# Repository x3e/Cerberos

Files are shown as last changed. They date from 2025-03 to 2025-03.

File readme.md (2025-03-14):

# Cerberos

## Issue
The screen is not working when powered from USB. In theory the internal CH552 voltage regulator should be able to provide enough current, and with a previous batch of screens, this was working. If you find the issue, please let us know by opening an issue or submitting a pull request.

## Compilation
To compile the software for this project, follow the instructions in the [ch55xduino](https://github.com/DeqingSun/ch55xduino) repository to set up your development environment. Use the following settings after selecting the CH552 board in Arduino:
 - Bootloader pin: P3.6 (D+) pull-up
 - Clock Source: 12 MHz (internal)
 - Upload method: USB
 - USB Settings: User Code w/ 0B USB ram

## License
This project is licensed under the Unlicense License. See the [LICENSE](LICENSE) file for details.

## Contact
If you have any questions or suggestions, feel free to open an issue.

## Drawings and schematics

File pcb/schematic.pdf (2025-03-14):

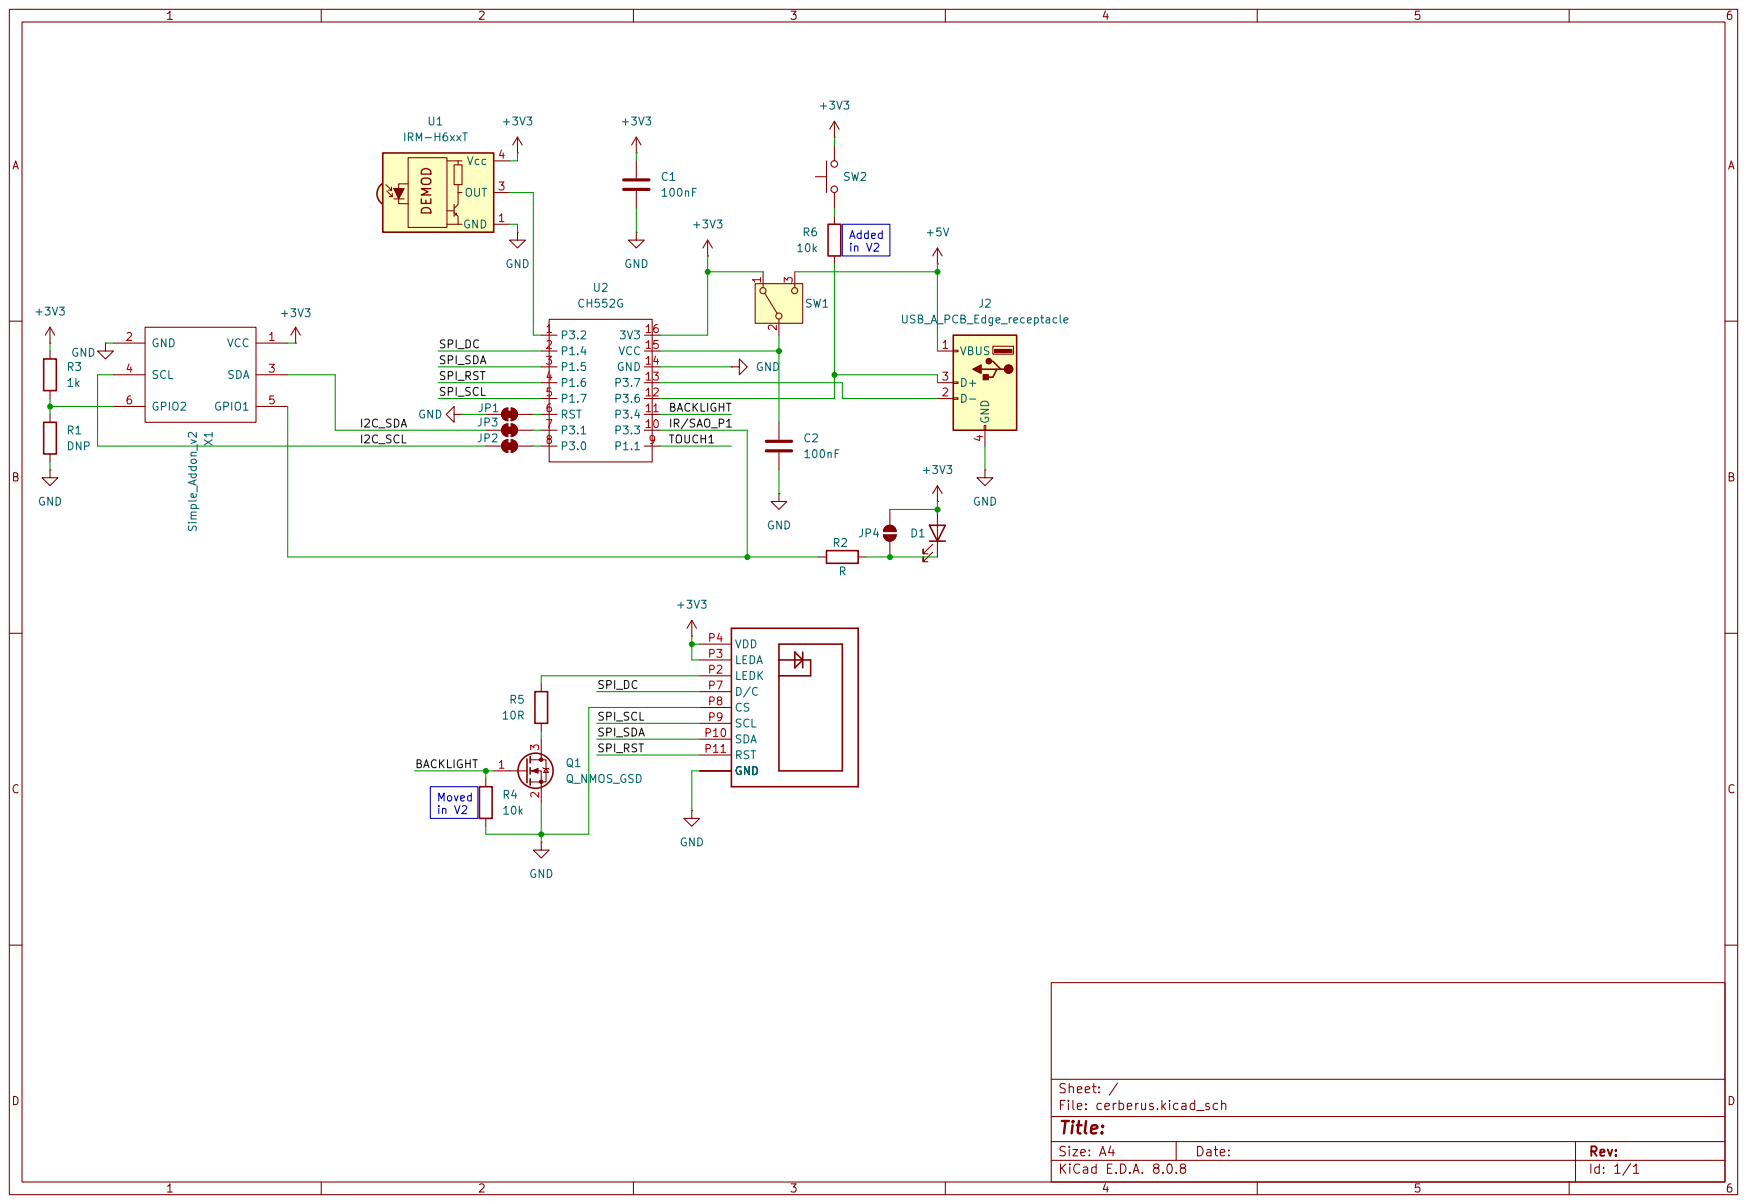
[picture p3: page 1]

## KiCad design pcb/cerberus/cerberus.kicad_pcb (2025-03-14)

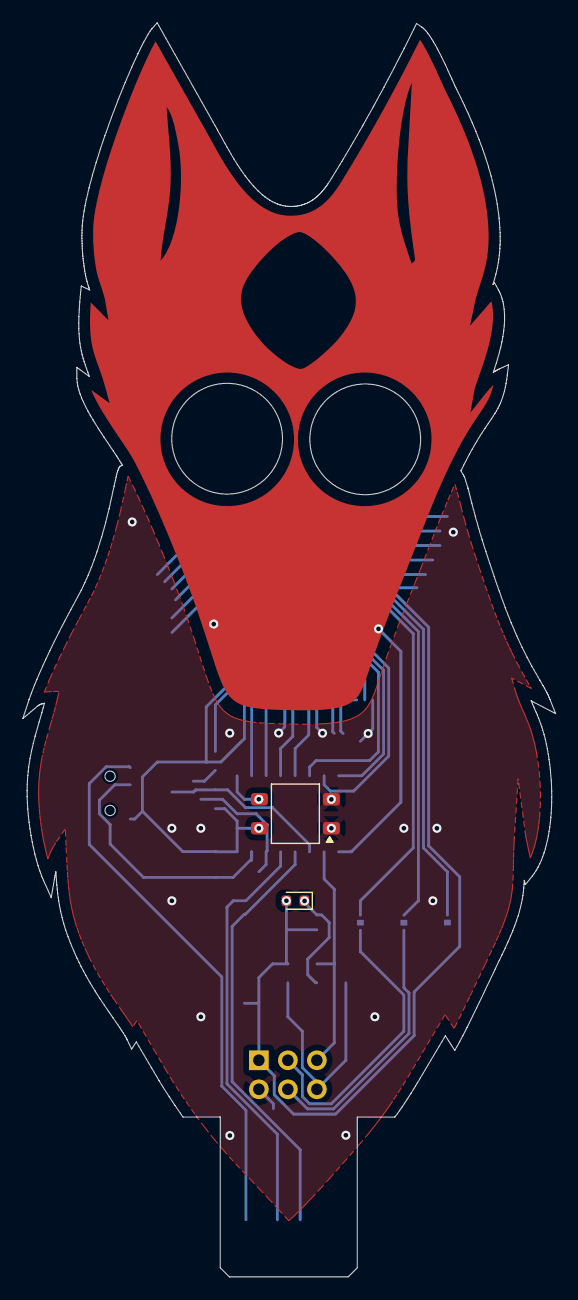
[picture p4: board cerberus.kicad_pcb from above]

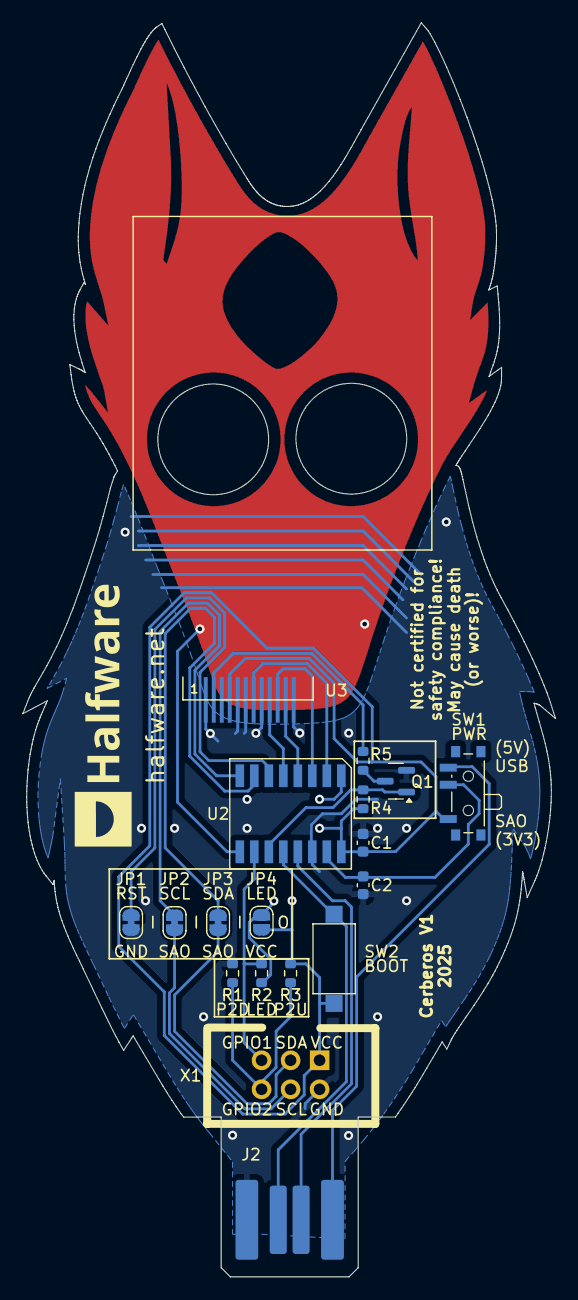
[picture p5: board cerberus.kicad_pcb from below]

Board: 2 copper layers, 46.7 x 109.8 mm, 20 parts (17 on the bottom side), 22 nets.

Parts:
C1, C2: 100nF; C_0603_1608Metric
D1: LED; LED_0603_1608Metric
J2: USB_A_PCB_Edge_receptacle
JP1, JP2, JP3: SolderJumper_2_Bridged; SolderJumper-2_P1.3mm_Bridged_RoundedPad1.0x1.5mm
JP4: SolderJumper_2_Open; SolderJumper-2_P1.3mm_Open_RoundedPad1.0x1.5mm
Q1: Q_NMOS_GSD; SOT-23
R1: DNP; R_0603_1608Metric
R2, R4, R5: R; R_0603_1608Metric
R3: 1k; R_0603_1608Metric
SW1: SW_SPDT; SW_SPDT_PCM12
SW2: SW_Push; SW_SPST_CK_RS282G05A3
U1: IRM-H6xxT; Everlight_IRM-H6xxT
U2: CH552G
U3: STP240240-0130A
X1: Simple_Addon_v2; Simple_Addon_v2-SAO-2x3

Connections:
+3V3: C1.1, D1.2 (A), JP4.2 (B), R3.1, R4.1, SW1.1 (A), SW2.2, U1.4 (Vcc), U2.16 (3V3), U3.P3 (LEDA), U3.P4 (VDD), X1.1 (VCC)
+5V: J2.1 (VBUS), SW1.3 (C)
/BACKLIGHT: Q1.1 (G), R4.2, U2.11 (P3.4)
/I2C_SCL: JP2.2 (B), X1.4 (SCL)
/I2C_SDA: JP3.2 (B), X1.3 (SDA)
/IR/SAO_P1: R2.1, U2.10 (P3.3), X1.5 (GPIO1)
/SPI_DC: U2.2 (P1.4), U3.P7 (D/C)
/SPI_RST: U2.4 (P1.6), U3.P11 (RST)
/SPI_SCL: U2.5 (P1.7), U3.P9 (SCL)
/SPI_SDA: U2.3 (P1.5), U3.P10 (SDA)
GND: C1.2, C2.2, J2.4 (GND), JP1.1 (A), Q1.2 (S), R1.2, U1.1 (GND), U1.2 (GND), U2.14 (GND), U3.P1 (GND), U3.P5 (GND), U3.P6 (GND), U3.P8 (CS), U3.P12 (GND), X1.2 (GND)
unnamed: D1.1 (K), JP4.1 (A), R2.2
unnamed: J2.3 (D+), SW2.1, U2.12 (P3.6)
unnamed: J2.2 (D-), U2.13 (P3.7)
unnamed: JP1.2 (B), U2.6 (RST)
unnamed: JP2.1 (A), U2.8 (P3.0)
unnamed: JP3.1 (A), U2.7 (P3.1)
unnamed: Q1.3 (D), R5.2
unnamed: C2.1, SW1.2 (B), U2.15 (VCC)
unnamed: U1.3 (OUT), U2.1 (P3.2)
unnamed: R5.1, U3.P2 (LEDK)
unnamed: R1.1, R3.2, X1.6 (GPIO2)

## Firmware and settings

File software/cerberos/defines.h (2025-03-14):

#ifndef DEFINES_H
#define DEFINES_H

/**
 * @brief st7789 bool enumeration definition
 */
typedef enum
{
    ST7789_BOOL_FALSE = 0x00,        /**< false */
    ST7789_BOOL_TRUE  = 0x01,        /**< true */
} st7789_bool_t;

/**
 * @brief st7789 gamma curve enumeration definition
 */
typedef enum
{
    ST7789_GAMMA_CURVE_1 = 0x1,        /**< g2.2 */
    ST7789_GAMMA_CURVE_2 = 0x2,        /**< g1.8 */
    ST7789_GAMMA_CURVE_3 = 0x4,        /**< g2.5 */
    ST7789_GAMMA_CURVE_4 = 0x8,        /**< g1.0 */
} st7789_gamma_curve_t;

/**
 * @brief st7789 tearing effect enumeration definition
 */
typedef enum
{
    ST7789_TEARING_EFFECT_V_BLANKING                = 0x0,        /**< v-blanking */
    ST7789_TEARING_EFFECT_V_BLANKING_AND_H_BLANKING = 0x1,        /**< v-blanking and h-blanking */
} st7789_tearing_effect_t;

/**
 * @brief st7789 order enumeration definition
 */
typedef enum
{
    ST7789_ORDER_PAGE_TOP_TO_BOTTOM    = (0 << 7),        /**< top to bottom */
    ST7789_ORDER_PAGE_BOTTOM_TO_TOP    = (1 << 7),        /**< bottom to top */
    ST7789_ORDER_COLUMN_LEFT_TO_RIGHT  = (0 << 6),        /**< left to right */
    ST7789_ORDER_COLUMN_RIGHT_TO_LEFT  = (1 << 6),        /**< right to left */
    ST7789_ORDER_PAGE_COLUMN_NORMAL    = (0 << 5),        /**< normal mode */
    ST7789_ORDER_PAGE_COLUMN_REVERSE   = (1 << 5),        /**< reverse mode */
    ST7789_ORDER_LINE_TOP_TO_BOTTOM    = (0 << 4),        /**< lcd refresh top to bottom */
    ST7789_ORDER_LINE_BOTTOM_TO_TOP    = (1 << 4),        /**< lcd refresh bottom to top */
    ST7789_ORDER_COLOR_RGB             = (0 << 3),        /**< rgb */
    ST7789_ORDER_COLOR_BGR             = (1 << 3),        /**< bgr */
    ST7789_ORDER_REFRESH_LEFT_TO_RIGHT = (0 << 2),        /**< lcd refresh left to right */
    ST7789_ORDER_REFRESH_RIGHT_TO_LEFT = (1 << 2),        /**< lcd refresh right to left */
} st7789_order_t;

/**
 * @brief st7789 rgb interface color format enumeration definition
 */
typedef enum
{
    ST7789_RGB_INTERFACE_COLOR_FORMAT_65K  = 0x5,        /**< 65k of rgb interface */
    ST7789_RGB_INTERFACE_COLOR_FORMAT_262K = 0x6,        /**< 262k of rgb interface */
} st7789_rgb_interface_color_format_t;

/**
 * @brief st7789 control interface color format enumeration definition
 */
typedef enum
{
    ST7789_CONTROL_INTERFACE_COLOR_FORMAT_12_BIT = 0x3,        /**< 12bit/pixel */
    ST7789_CONTROL_INTERFACE_COLOR_FORMAT_16_BIT = 0x5,        /**< 16bit/pixel */
    ST7789_CONTROL_INTERFACE_COLOR_FORMAT_18_BIT = 0x6,        /**< 18bit/pixel */
} st7789_control_interface_color_format_t;

/**
 * @brief st7789 color enhancement mode enumeration definition
 */
typedef enum
{
    ST7789_COLOR_ENHANCEMENT_MODE_OFF            = 0x0,        /**< off */
    ST7789_COLOR_ENHANCEMENT_MODE_USER_INTERFACE = 0x1,        /**< user interface mode */
    ST7789_COLOR_ENHANCEMENT_MODE_STILL_PICTURE  = 0x2,        /**< still picture */
    ST7789_COLOR_ENHANCEMENT_MODE_MOVING_IMAGE   = 0x3,        /**< moving image */
} st7789_color_enhancement_mode_t;

/**
 * @brief st7789 color enhancement level enumeration definition
 */
typedef enum
{
    ST7789_COLOR_ENHANCEMENT_LEVEL_LOW    = 0x0,        /**< low enhancement */
    ST7789_COLOR_ENHANCEMENT_LEVEL_MEDIUM = 0x1,        /**< medium enhancement */
    ST7789_COLOR_ENHANCEMENT_LEVEL_HIGH   = 0x3,        /**< high enhancement */
} st7789_color_enhancement_level_t;
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

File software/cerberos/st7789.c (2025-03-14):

#include "st7789.h"
#include <Arduino.h>

#include "defines.h"

#define SPI_transfer(data) SPI0_DATA = data; while (S0_FREE == 0)
#define SPI_writeByte(data) while (S0_FREE == 0); SPI0_DATA = data
#define SPI_finishByte() while(S0_FREE == 0)

#define MAX_CIRCLE_RADIUS 32

uint8_t circleSize = -1;
uint8_t circleBuffer[MAX_CIRCLE_RADIUS];

volatile uint16_t waitCounter = 0;

static void writeNBytes(uint16_t n, uint16_t color) {
  for(uint16_t i=0; i<n; i++) {
    SPI_writeByte(color >> 8);
    SPI_writeByte(color);
  }
  SPI_finishByte();
}

inline void setParam(uint8_t command, uint8_t data) {
  SPI_transfer(command);
  digitalWrite(DC_PIN, HIGH);
  SPI_transfer(data);
  digitalWrite(DC_PIN, LOW);
}

void st7789_init() {
  pinMode(RST_PIN, OUTPUT);
  digitalWrite(RST_PIN, LOW);
  delay(25);
  pinMode(DC_PIN, OUTPUT);
  digitalWrite(DC_PIN, LOW);
  digitalWrite(RST_PIN, HIGH);
  delay(250);

  SPI0_CTRL = bS0_MOSI_OE | bS0_SCK_OE;
  SPI0_CK_SE = F_CPU / 6000000;

  SPI_transfer(ST7789_CMD_INVON);
  SPI_transfer(ST7789_CMD_SLPOUT);
  delay(500);

  setParam(ST7789_CMD_MADCTL, ST7789_BASIC_DEFAULT_ACCESS);
  setParam(ST7789_CMD_COLMOD, (ST7789_BASIC_DEFAULT_RGB_INTERFACE_COLOR_FORMAT << 4) | (ST7789_BASIC_DEFAULT_CONTROL_INTERFACE_COLOR_FORMAT << 0));
  SPI_transfer(ST7789_CMD_DISPON);
}

static void setDrawingArea(uint8_t x1, uint8_t x2, uint8_t y1, uint8_t y2) {
  SPI_transfer(ST7789_CMD_CASET);
  digitalWrite(DC_PIN, HIGH);
  SPI_writeByte(0x00);
  SPI_writeByte(x1);
  SPI_writeByte(0x00);
  SPI_writeByte(x2);
  SPI_finishByte();
  digitalWrite(DC_PIN, LOW);

  SPI_transfer(ST7789_CMD_RASET);
  digitalWrite(DC_PIN, HIGH);
  SPI_writeByte(0x00);
  SPI_writeByte(y1);
  SPI_writeByte(0x00);
  SPI_writeByte(y2);
  SPI_finishByte();
  digitalWrite(DC_PIN, LOW);
}

void st7789_HLine(uint8_t x1, uint8_t x2, uint8_t y, uint16_t color) {
  setDrawingArea(x1, x2, y, y);
  
  SPI_transfer(ST7789_CMD_RAMWR);
  digitalWrite(DC_PIN, HIGH);
  
  writeNBytes(x2 - x1 + 1, color);

  digitalWrite(DC_PIN, LOW);
}

void st7789_FillRect(uint8_t x1, uint8_t x2, uint8_t y1, uint8_t y2, uint16_t color) {
  setDrawingArea(x1, x2, y1, y2);

  SPI_transfer(ST7789_CMD_RAMWR);
  digitalWrite(DC_PIN, HIGH);

  uint16_t area = (x2 - x1 + 1) * (y2 - y1 + 1);
  writeNBytes(area, color);

  digitalWrite(DC_PIN, LOW);
}

static void fillCircleBuffer(uint8_t r) {
  if (circleSize != r) {
    uint8_t t1 = r/16;
    uint8_t cx = r;
    uint8_t cy = 0;
    while(cx >= cy) {
      circleBuffer[cy] = cx;
      cy++;
      t1 += cy;
      if (cx > t1) {
        t1 -= cx;
        cx--;
        circleBuffer[cx] = cy;
      }
    }
  }
}

void st7789_FillCircle(uint8_t x, uint8_t y, uint8_t r, uint16_t color) {
  if (r > MAX_CIRCLE_RADIUS) return;
  fillCircleBuffer(r);
  for (uint8_t l=0; l<r; l++) {
    st7789_HLine(x-circleBuffer[l], x+circleBuffer[l], y-l, color);
    if (l > 0)
      st7789_HLine(x-circleBuffer[l], x+circleBuffer[l], y+l, color);
  }
}

inline uint8_t getCircleLineW(uint8_t ys, uint8_t y, uint8_t r) {
  uint8_t d = ys > y ? ys - y : y - ys;
  return d < r ? circleBuffer[d] : 0;
}

void st7789_MoveFilledCircle(uint8_t x1, uint8_t x2, uint8_t y1, uint8_t y2, uint8_t r, uint16_t backgroundColor, uint16_t circleColor) {
  if (r > MAX_CIRCLE_RADIUS) return;
  fillCircleBuffer(r);
  for (uint8_t y=(y1 < y2 ? y1 - r : y2 - r); y<240; y++) {
    uint8_t w1 = getCircleLineW(y1, y, r);
    uint8_t w2 = getCircleLineW(y2, y, r);
    uint8_t x1s = x1 - w1;
    uint8_t x1e = x1 + w1;
    uint8_t x2s = x2 - w2;
    uint8_t x2e = x2 + w2;
    if (w1 && w2 && x1s <= x2e && x2s <= x1e) {
      if (x1s < x2s) st7789_HLine(x1s, x2s - 1, y, backgroundColor);
      if (x1e > x2e) st7789_HLine(x2e+1, x1e, y, backgroundColor);
    } else if (w1)
      st7789_HLine(x1s, x1e, y, backgroundColor);
    if (w2)
      st7789_HLine(x2s, x2e, y, circleColor);
  }
}
